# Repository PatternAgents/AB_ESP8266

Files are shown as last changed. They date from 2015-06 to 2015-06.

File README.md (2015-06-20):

# AB_ESP8266
=============

**AB_ESP8266** is a Wi-Fi Interface that fits in a standard XBee socket. 

**Agent Bees** are standard XBEE socket implementations that implement
various reference and interface circuits compatible with the XBee ecosystem.
These reference designs can serve as starting templates for user designs.

**AB_ESP8266** includes an ESP8266-07 format Wi-Fi module,
and status LED's. 

---------------------------------------

For ESP8266 Documentation (esp. toolchain info) see [NurdSpace](https://nurdspace.nl/ESP8266)

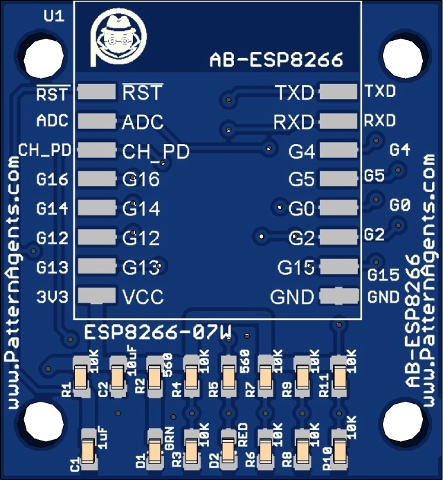
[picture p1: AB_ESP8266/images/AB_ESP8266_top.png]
thingSoC AB_ESP8266
[  
*AB_ESP8266*](https://github.com/patternagents/AB_ESP8266)

---------------------------------------

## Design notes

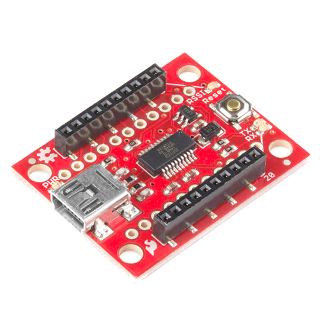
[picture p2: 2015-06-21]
AB_ESP8266/images/SFE_Xbee_Explorer.png

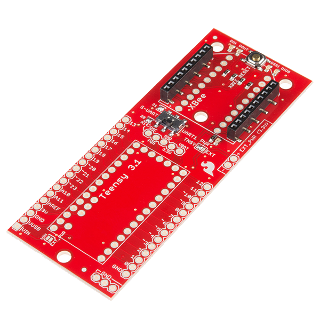
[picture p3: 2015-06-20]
AB_ESP8266/images/SFE_Teensy_XBee.png

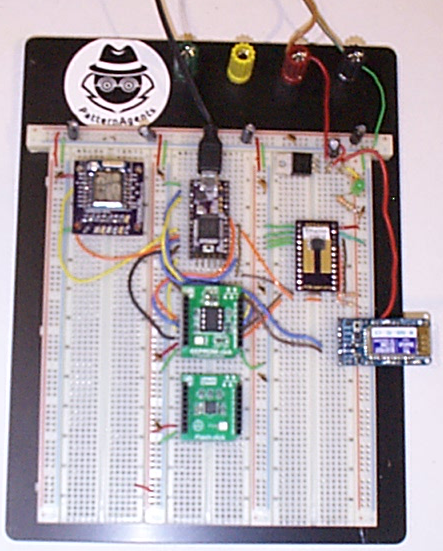
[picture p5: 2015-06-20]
AB_ESP8266/images/AB_ESP8266_img2.png

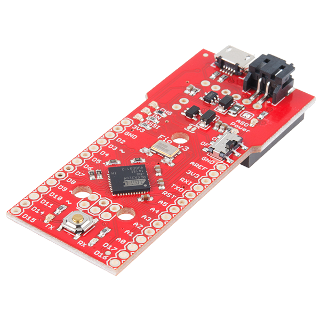
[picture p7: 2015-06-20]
AB_ESP8266/images/SFE_fio.png

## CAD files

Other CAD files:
AB_ESP8266/eagleUp/AB_ESP8266.skp

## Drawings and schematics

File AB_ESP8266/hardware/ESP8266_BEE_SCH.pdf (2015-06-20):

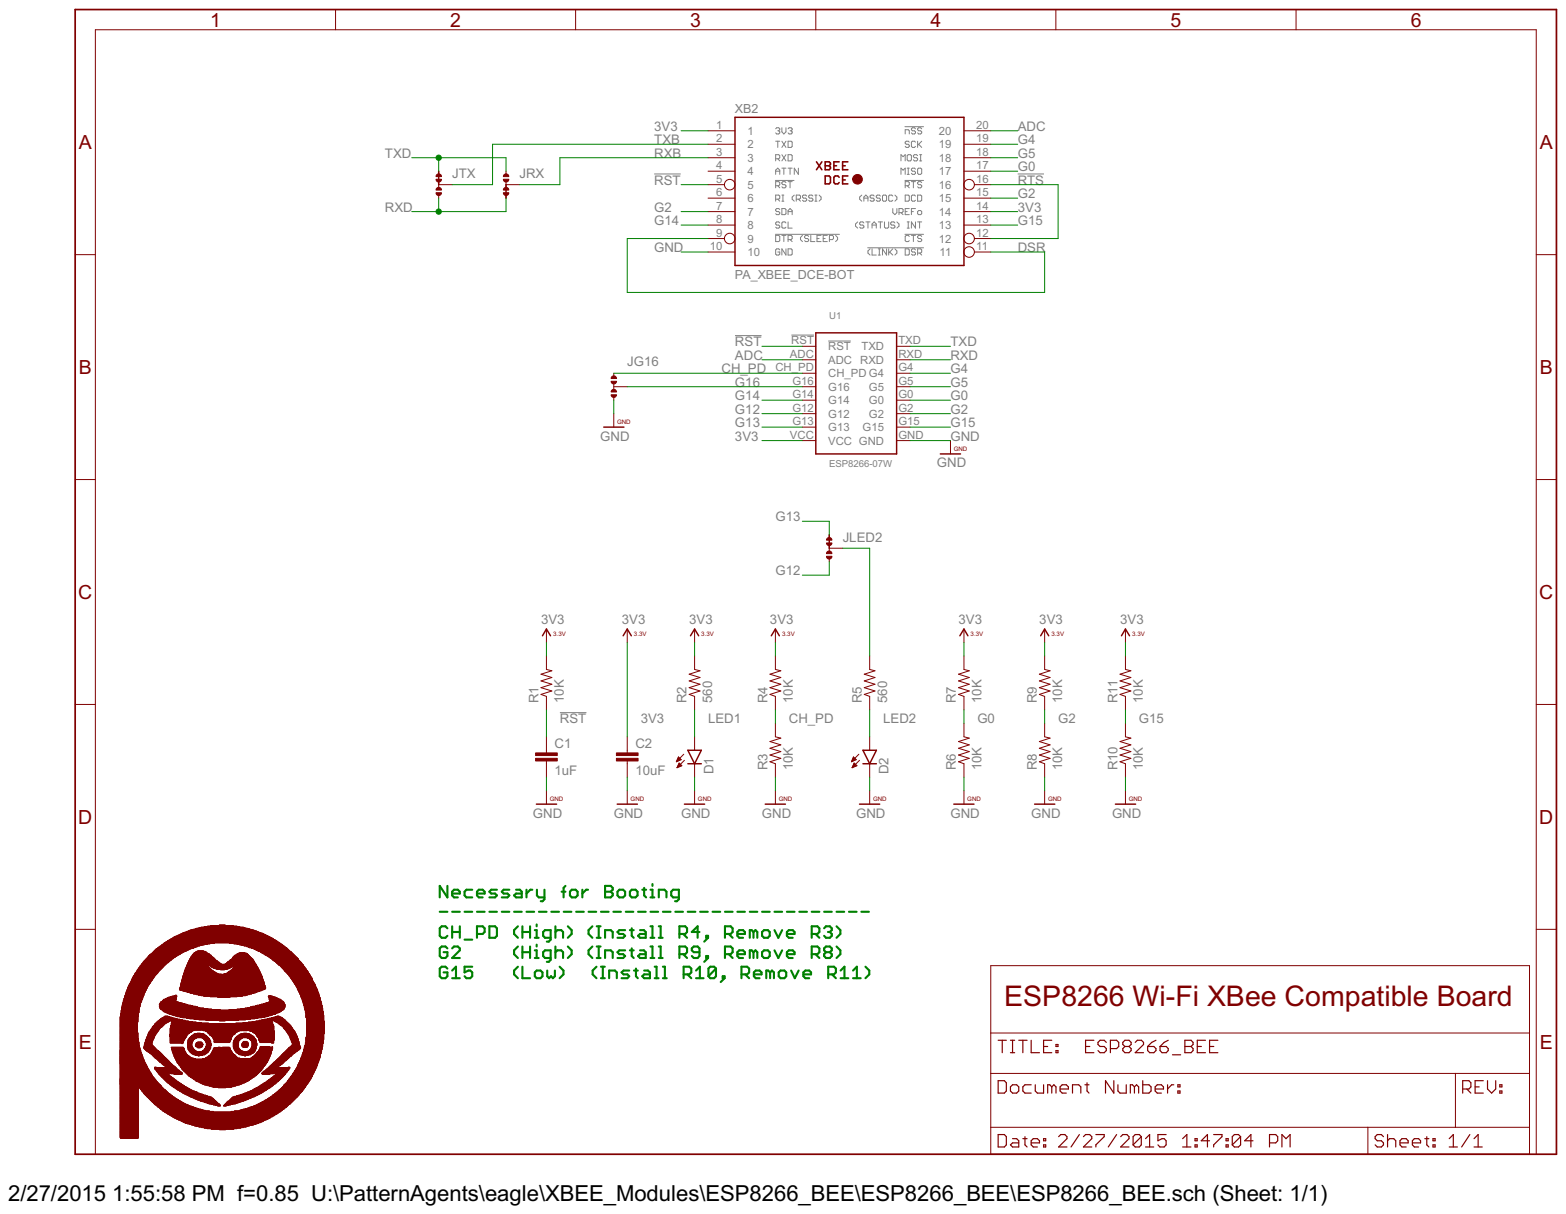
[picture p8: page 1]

3 | 18
4 5 | 17

ESP8266 Wi-Fi XBee Compatible Board

2/27/2015 1:55:58 PM f=0.85 U:\PatternAgents\eagle\XBEE_Modules\ESP8266_BEE\ESP8266_BEE\ESP8266_BEE.sch (Sheet: 1/1)

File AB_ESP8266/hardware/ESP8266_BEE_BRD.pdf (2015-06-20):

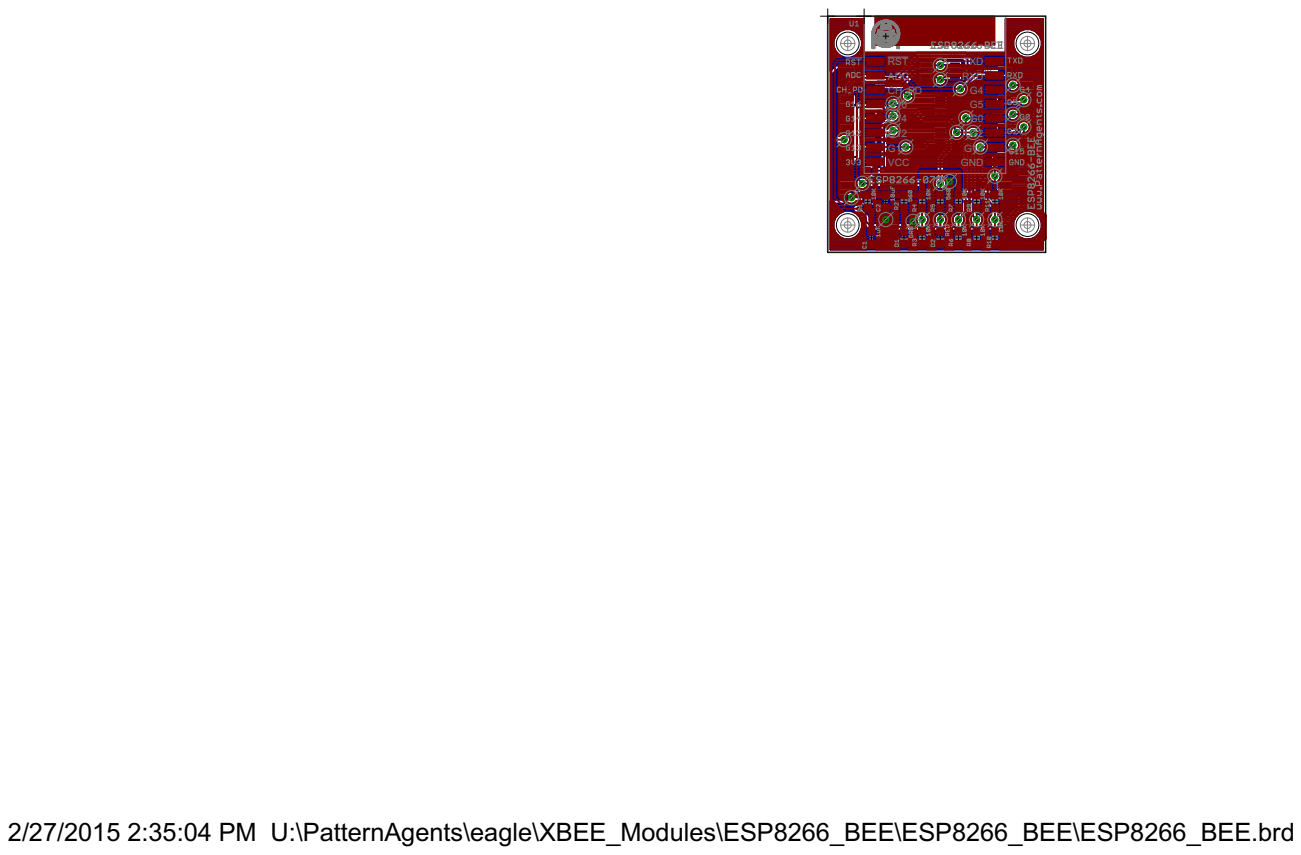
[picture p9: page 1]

2/27/2015 2:35:04 PM U:\PatternAgents\eagle\XBEE_Modules\ESP8266_BEE\ESP8266_BEE\ESP8266_BEE.brd

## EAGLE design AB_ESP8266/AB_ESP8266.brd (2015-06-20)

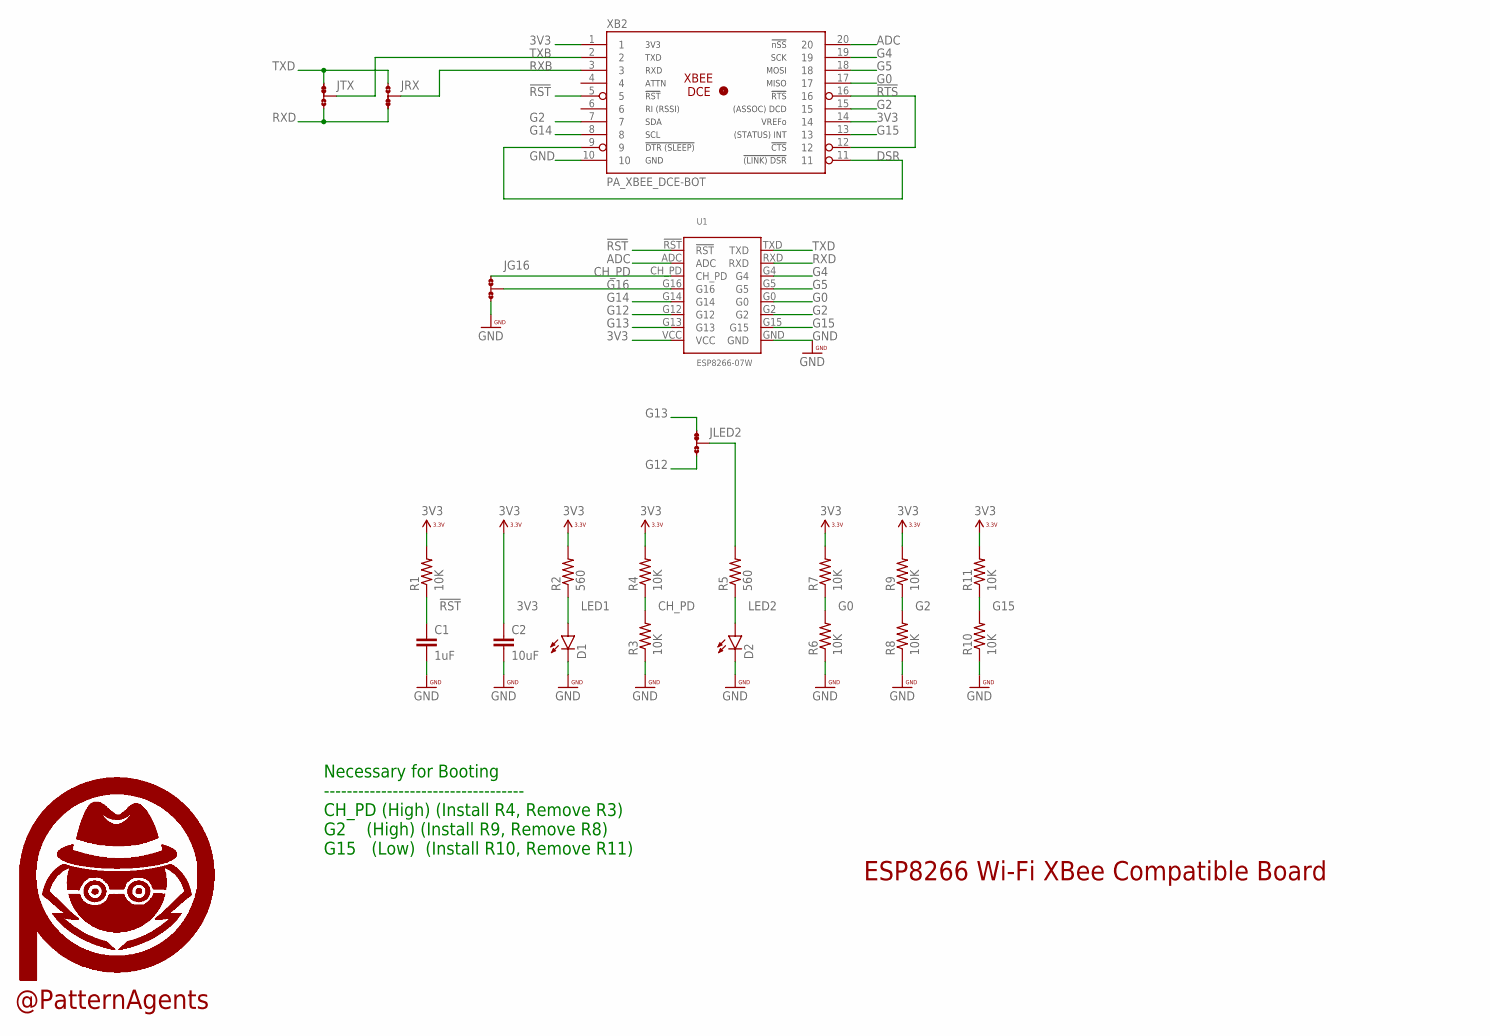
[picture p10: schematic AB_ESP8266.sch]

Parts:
C1: 1uF; 0603-CAP
C2: 10uF; 0603-CAP
D1, D2: LED0603; LED-0603
JG16: JMP-3-NO
JLED2: JMP-3-1_2
JRX: JMP-3-2_3
JTX: JMP-3-1_2
R1, R3, R4, R6, R7, R8, R9, R10, R11: 10K; 0603-RES
R2, R5: 560; 0603-RES
U1: ESP8266-07W
U$18, U$19: PA_LOGO_SYMSMALL; PA_LOGO_AGENT_SMALL_SYM
XB2: PA_XBEE_DCE-BOT; PA_XBEE_SMD_BOT

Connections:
3V3: C2.1, R1.2, R2.2, R4.2, R7.2, R9.2, R11.2, U1.VCC, XB2.1, XB2.14
!RST: C1.1, R1.1, U1.!RST, XB2.5
!RTS: XB2.12, XB2.16
ADC: U1.ADC, XB2.20
CH_PD: JG16.1, R3.2, R4.1, U1.CH_PD
DSR: XB2.9, XB2.11
G0: R6.2, R7.1, U1.G0, XB2.17
G2: R8.2, R9.1, U1.G2, XB2.7, XB2.15
G4: U1.G4, XB2.19
G5: U1.G5, XB2.18
G12: JLED2.3, U1.G12
G13: JLED2.1, U1.G13
G14: U1.G14, XB2.8
G15: R10.2, R11.1, U1.G15, XB2.13
G16: JG16.2, U1.G16
GND: C1.2, C2.2, D1.C, D2.C, JG16.3, R3.1, R6.1, R8.1, R10.1, U1.GND, XB2.10
JLED2: JLED2.2, R5.2
LED1: D1.A, R2.1
LED2: D2.A, R5.1
RXB: JRX.2, XB2.3
RXD: JRX.3, JTX.3, U1.RXD
TXB: JTX.2, XB2.2
TXD: JRX.1, JTX.1, U1.TXD

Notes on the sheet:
Necessary for Booting ----------------------------------- CH_PD (High) (Install R4, Remove R3) G2 (High) (Install R9, Remove R8) G15 (Low) (Install R10, Remove R11)
ESP8266 Wi-Fi XBee Compatible Board
@PatternAgents

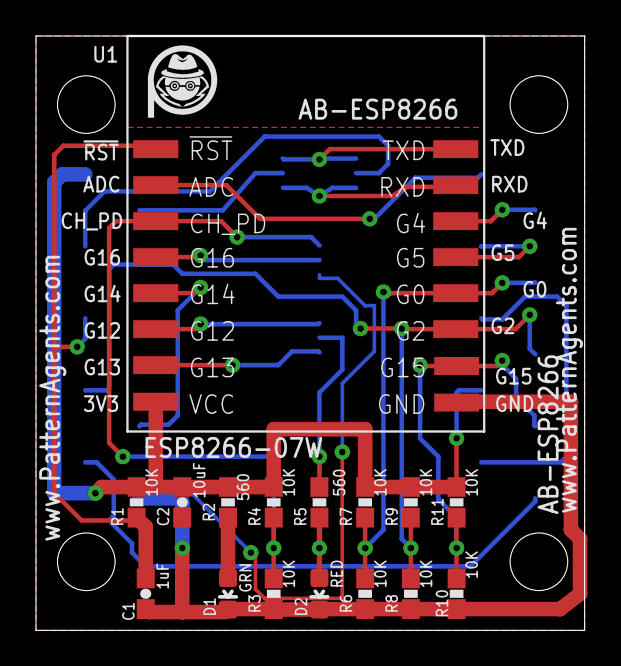
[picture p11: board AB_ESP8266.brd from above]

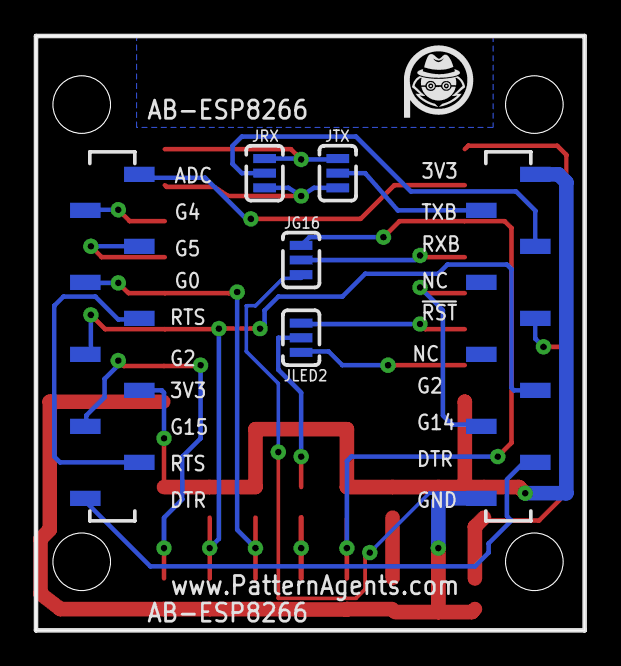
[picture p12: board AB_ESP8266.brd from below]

Board: 2 copper layers, 30.5 x 33.0 mm, 23 parts (5 on the bottom side), 23 nets.

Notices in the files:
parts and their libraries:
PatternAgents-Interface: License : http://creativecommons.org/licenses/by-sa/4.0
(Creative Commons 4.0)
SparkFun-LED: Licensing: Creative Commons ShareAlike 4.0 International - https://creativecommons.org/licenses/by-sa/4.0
